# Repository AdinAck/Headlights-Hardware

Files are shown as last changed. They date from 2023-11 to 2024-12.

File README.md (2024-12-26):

# Headlights-Hardware

This repo contains the PCB design files for the headlights board.



# Design Considerations

- high voltage compliance required great care for component selection and stray interactions
- the very high switching frequency of the half-bridge made the position and proximity of the components very important
- device failures must result in a safe state

---
[Firmware](https://github.com/AdinAck/Headlights-Firmware) | [App](https://github.com/AdinAck/Headlights-App)

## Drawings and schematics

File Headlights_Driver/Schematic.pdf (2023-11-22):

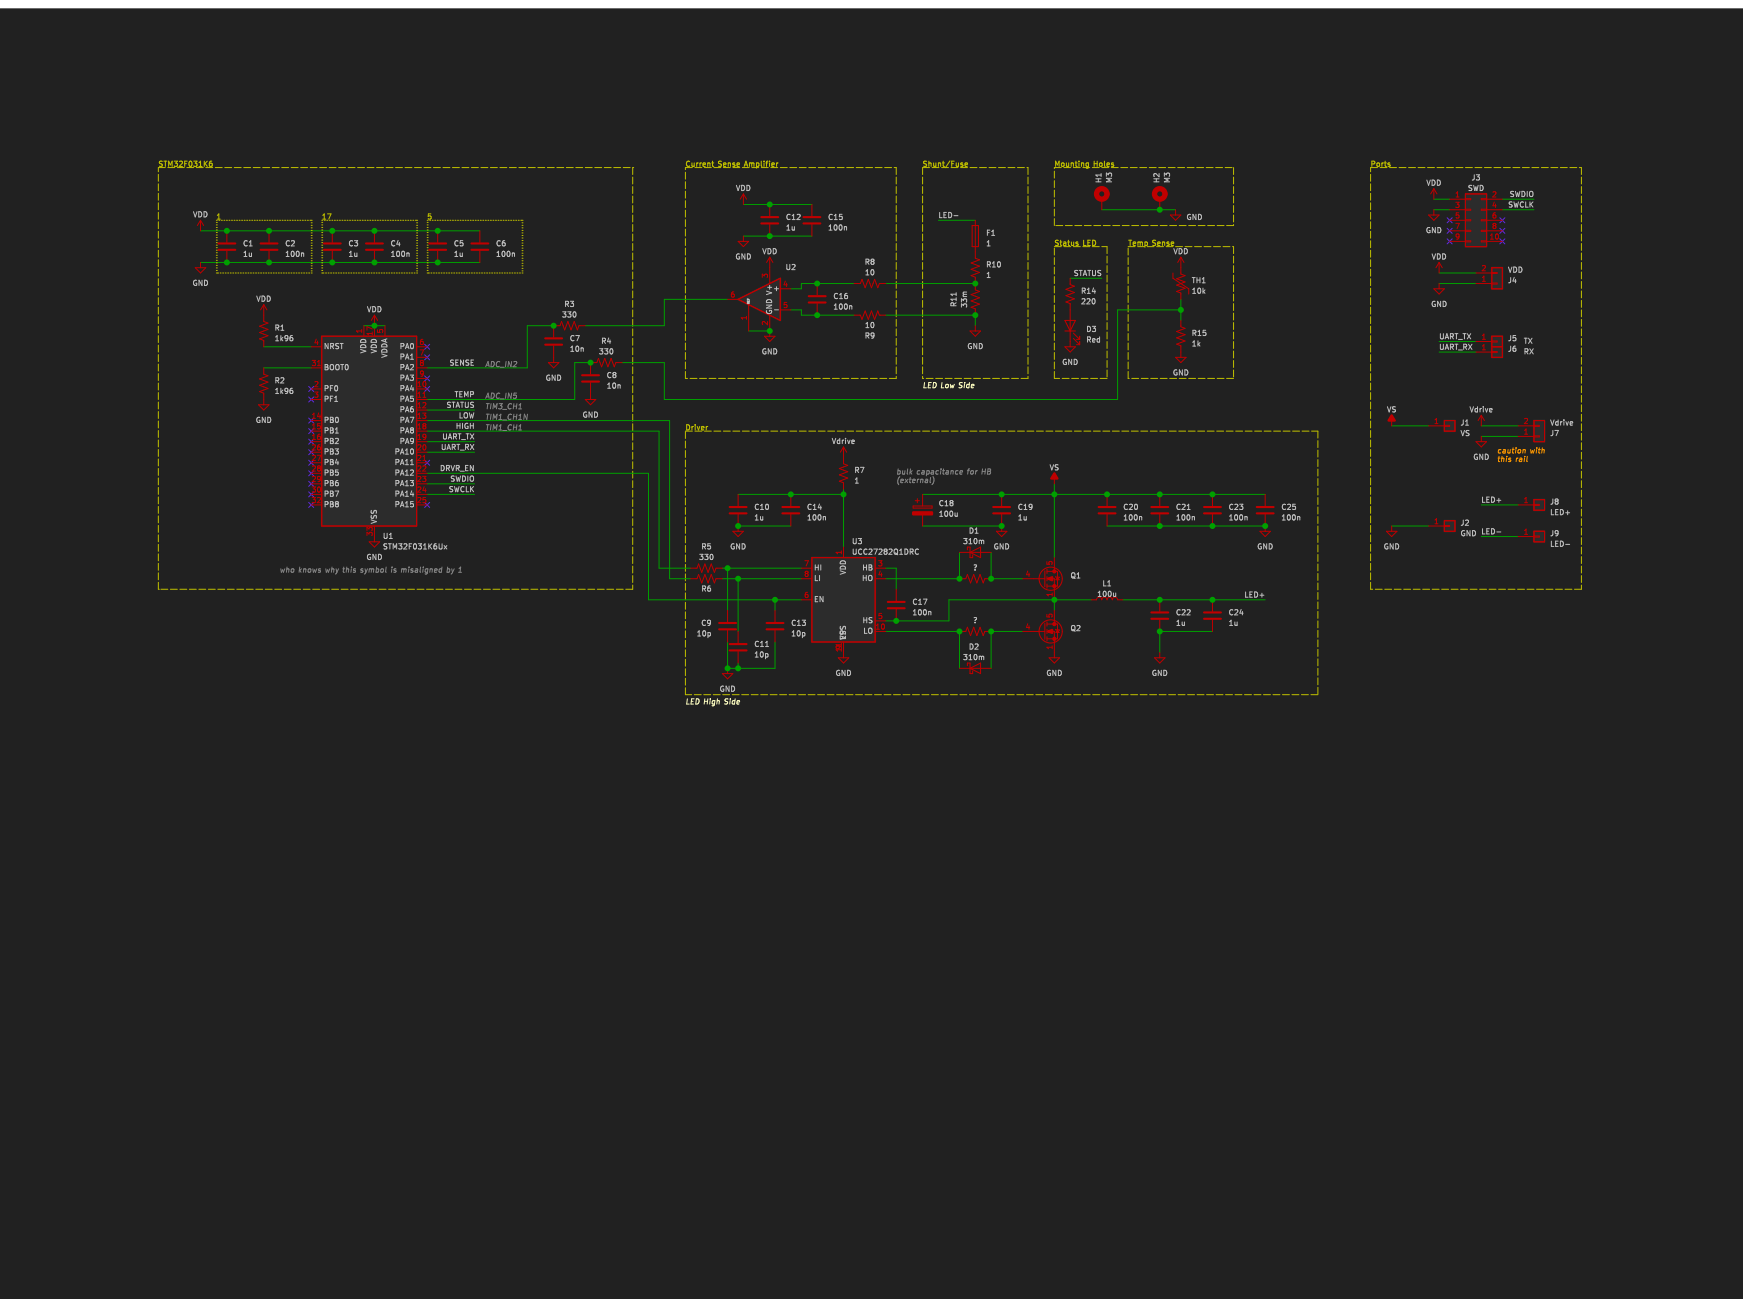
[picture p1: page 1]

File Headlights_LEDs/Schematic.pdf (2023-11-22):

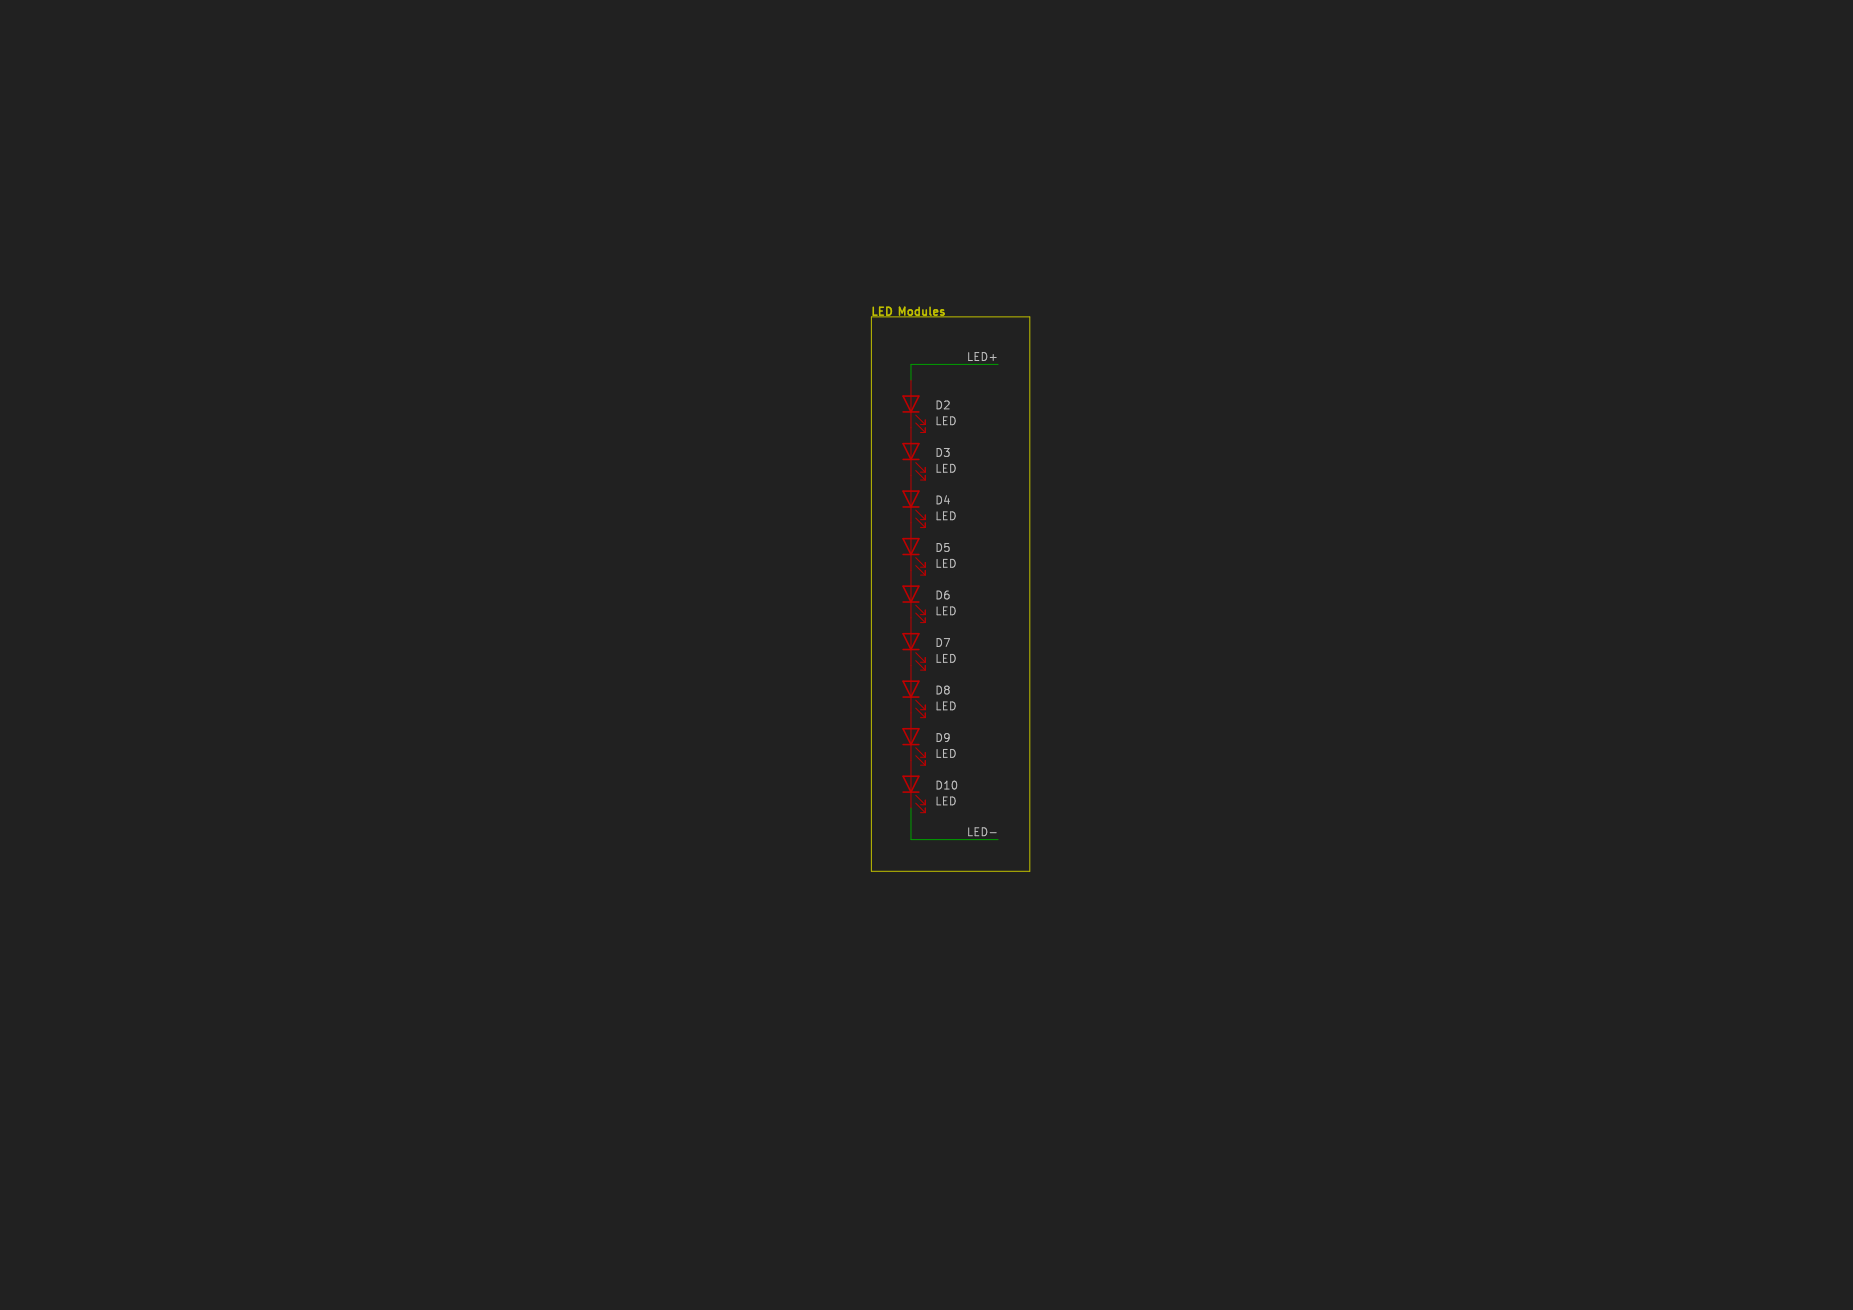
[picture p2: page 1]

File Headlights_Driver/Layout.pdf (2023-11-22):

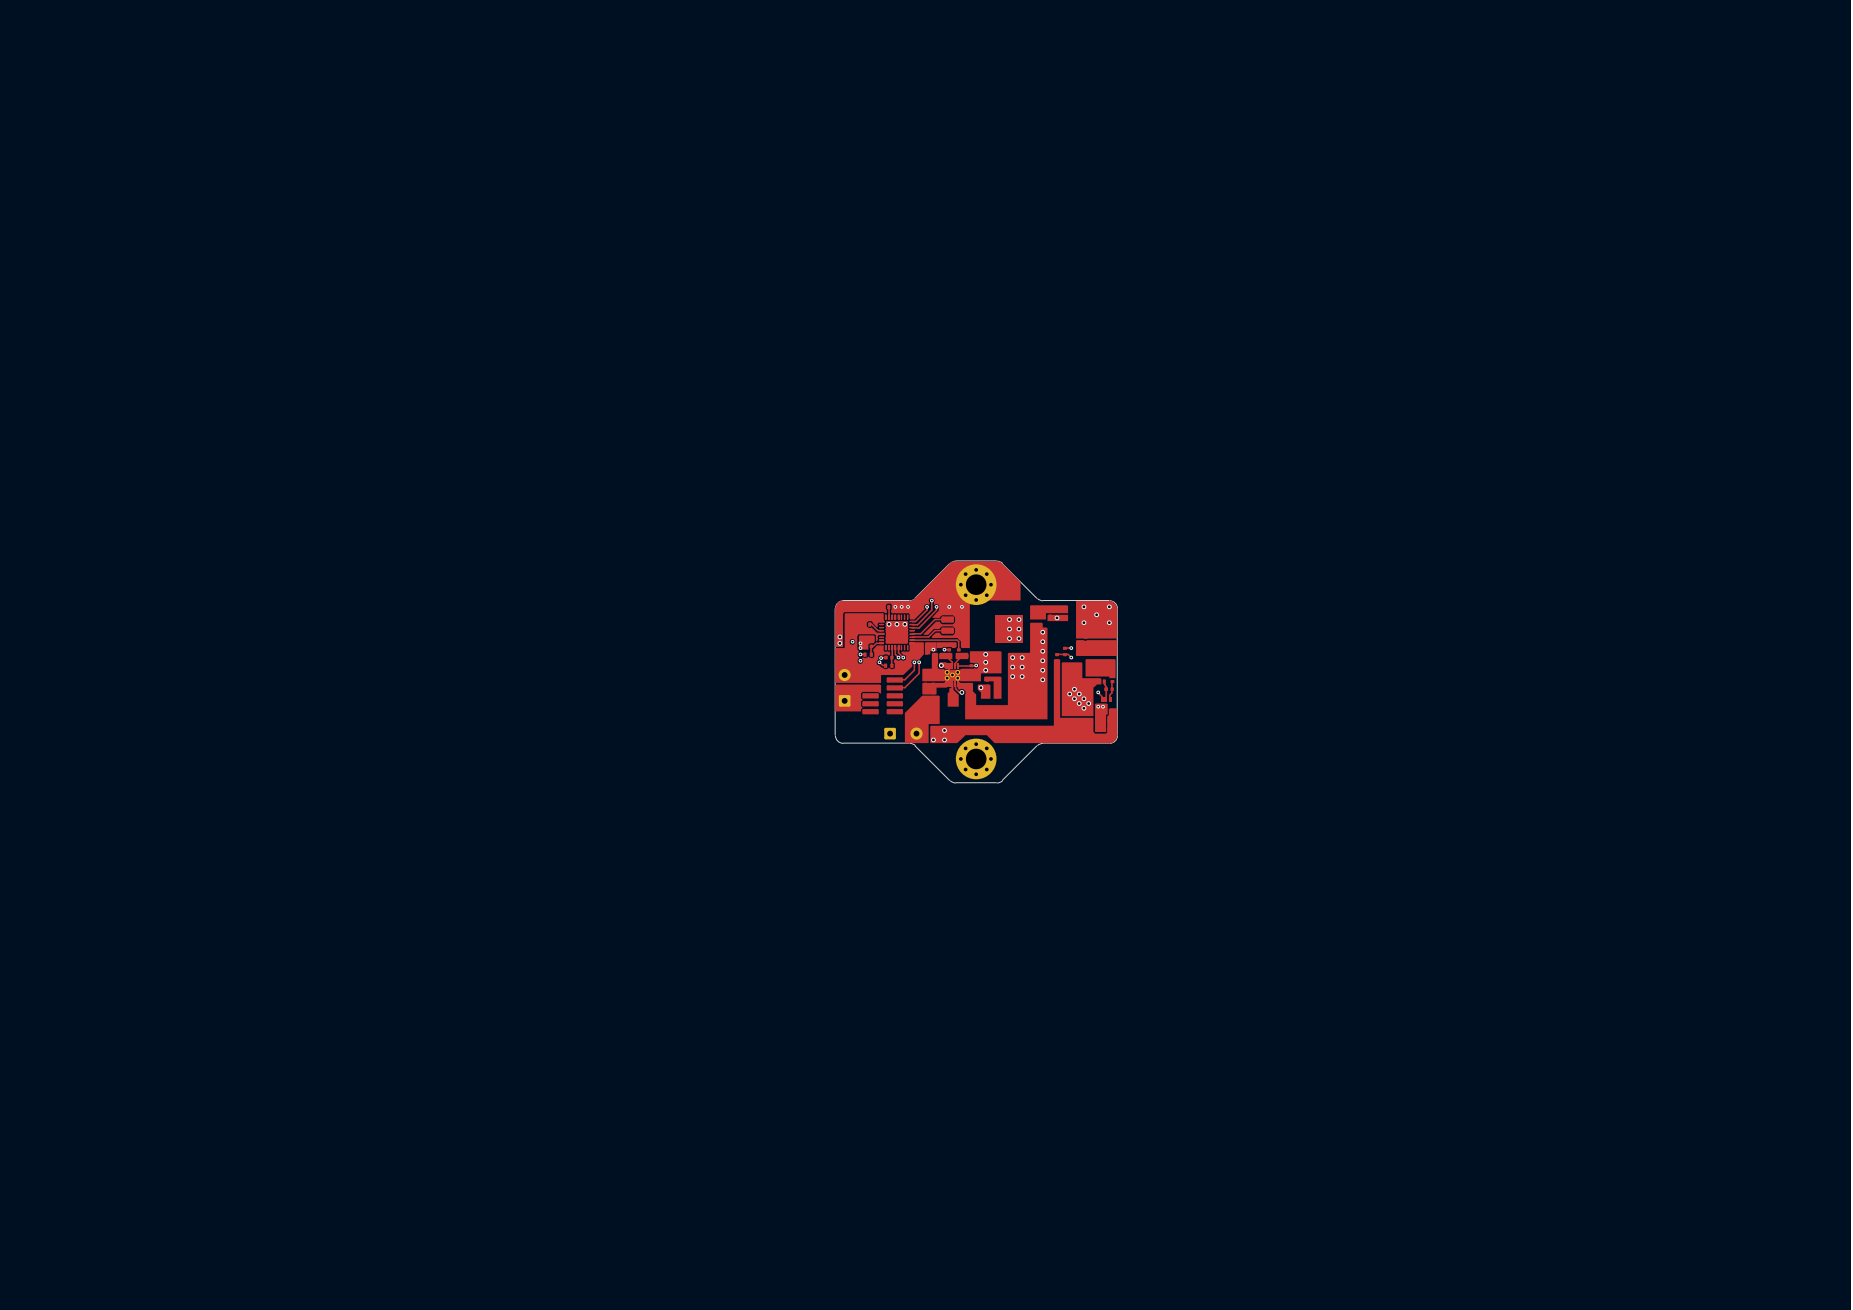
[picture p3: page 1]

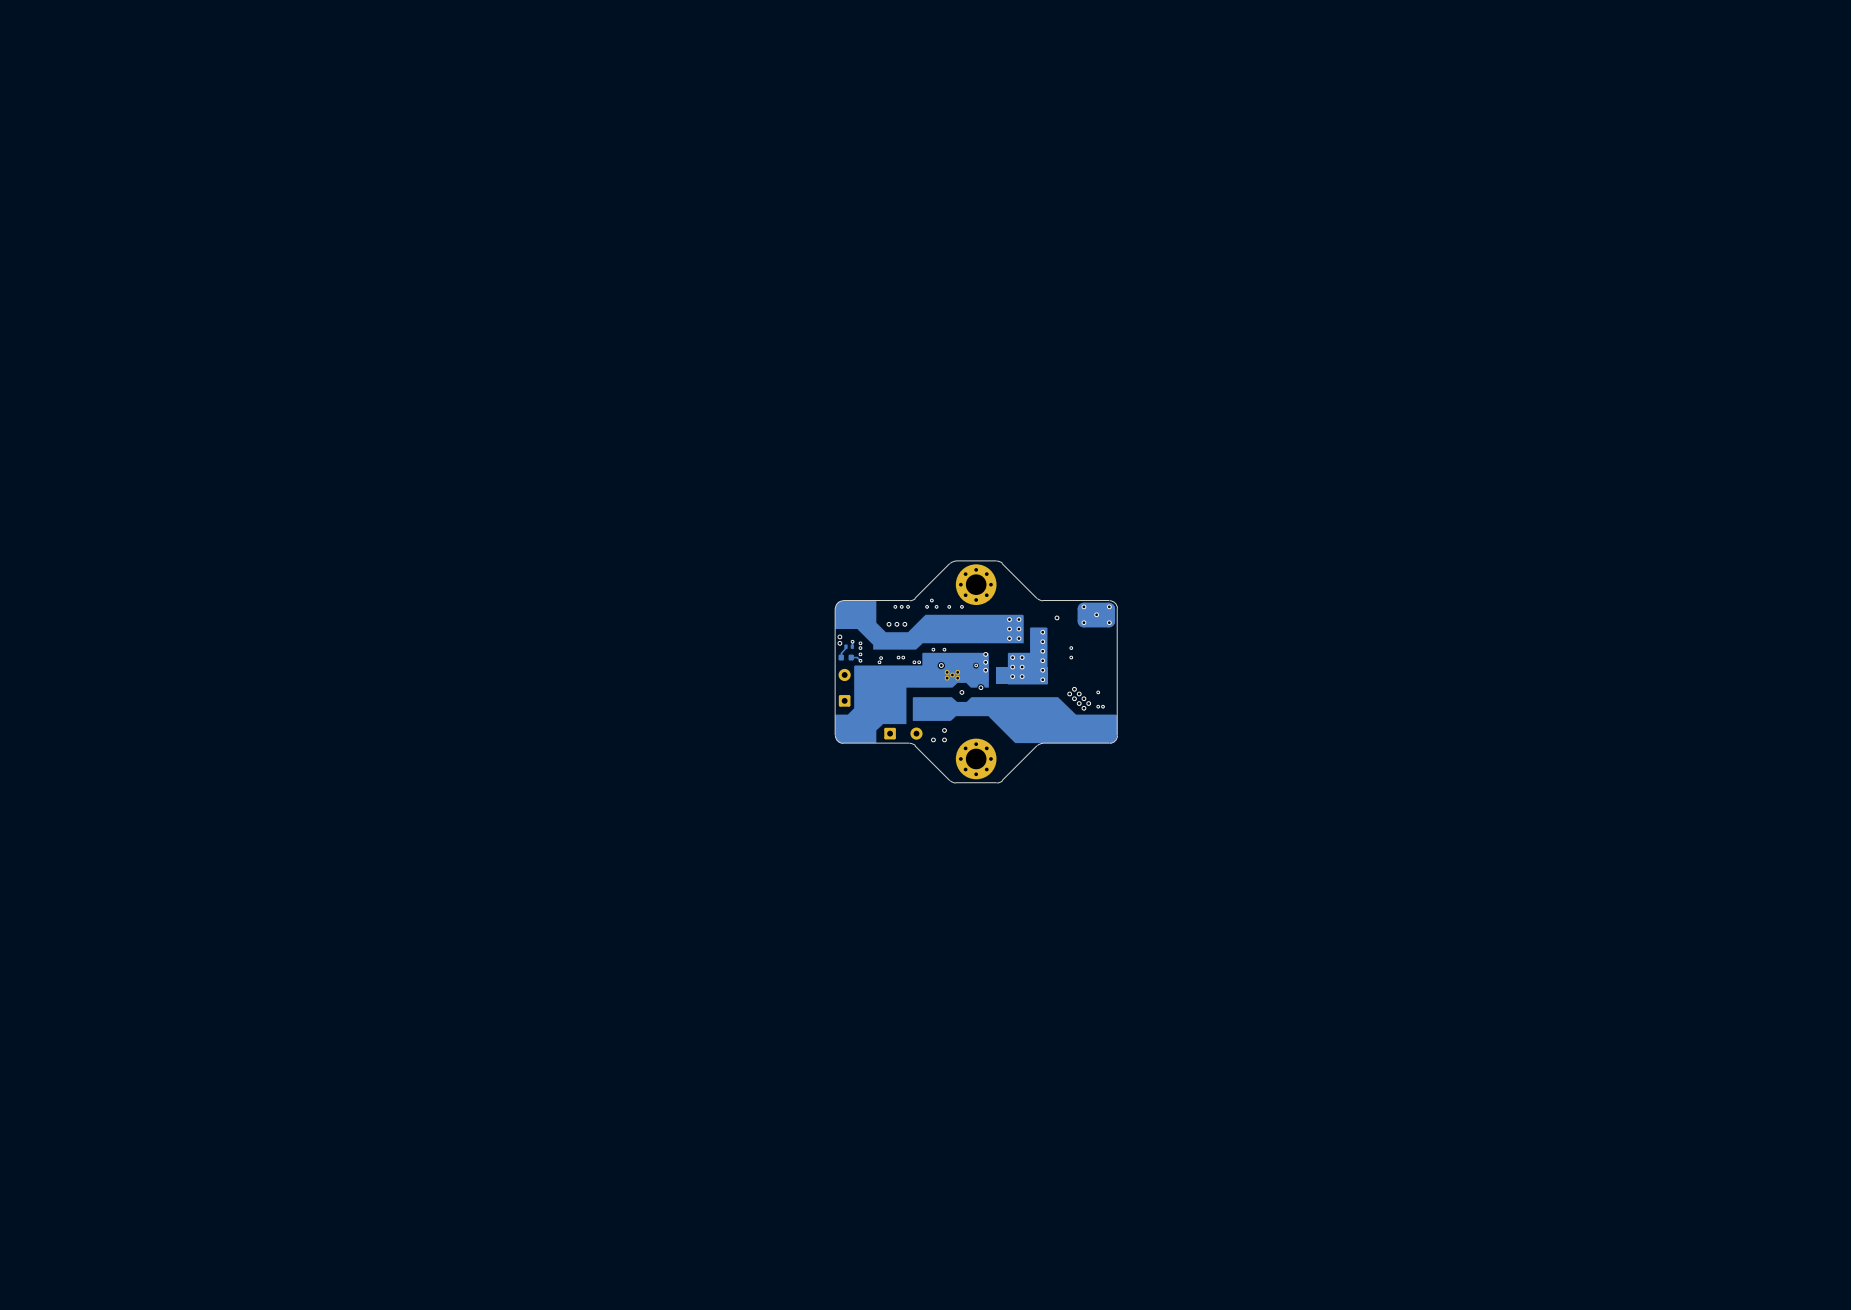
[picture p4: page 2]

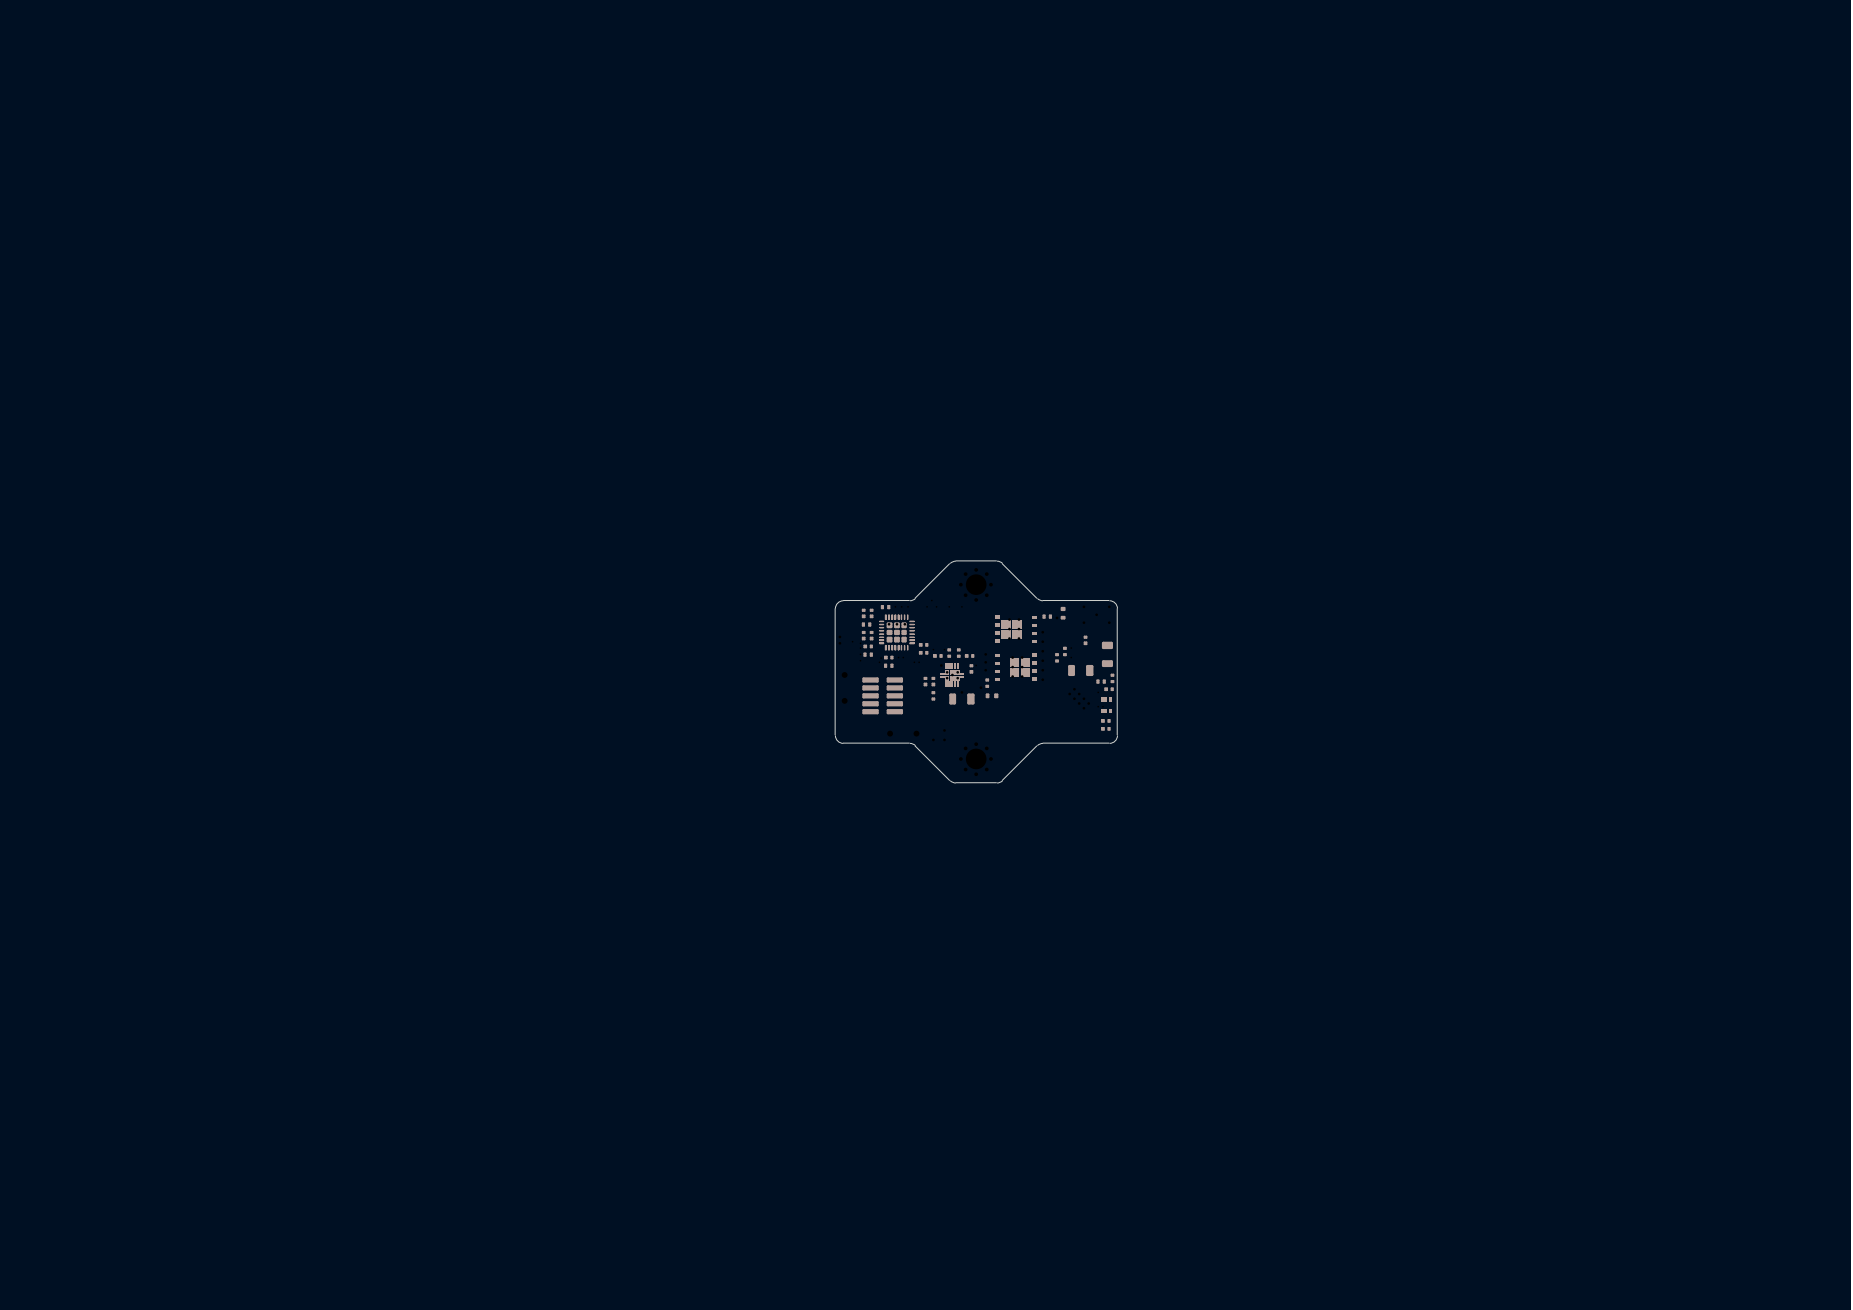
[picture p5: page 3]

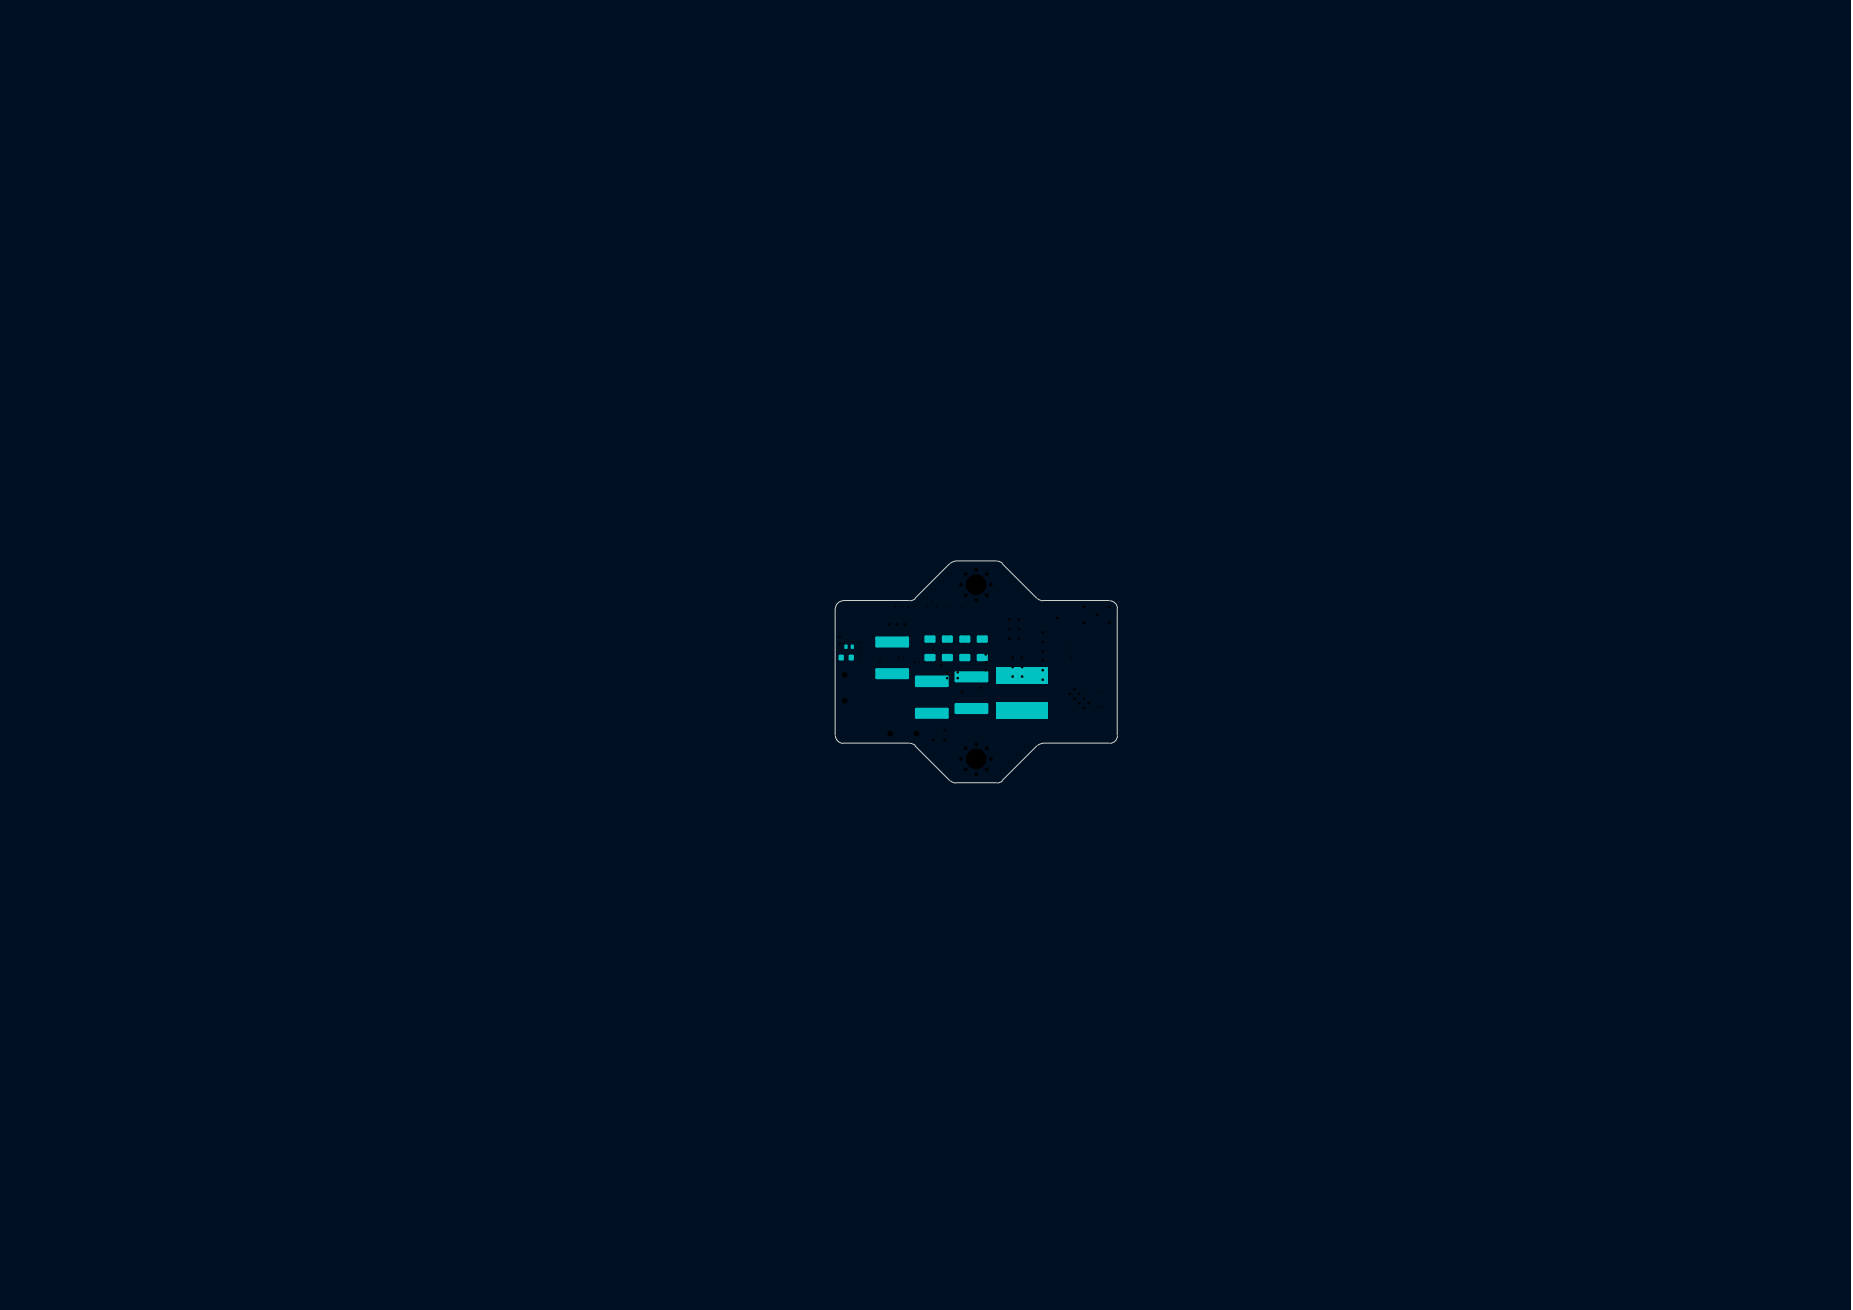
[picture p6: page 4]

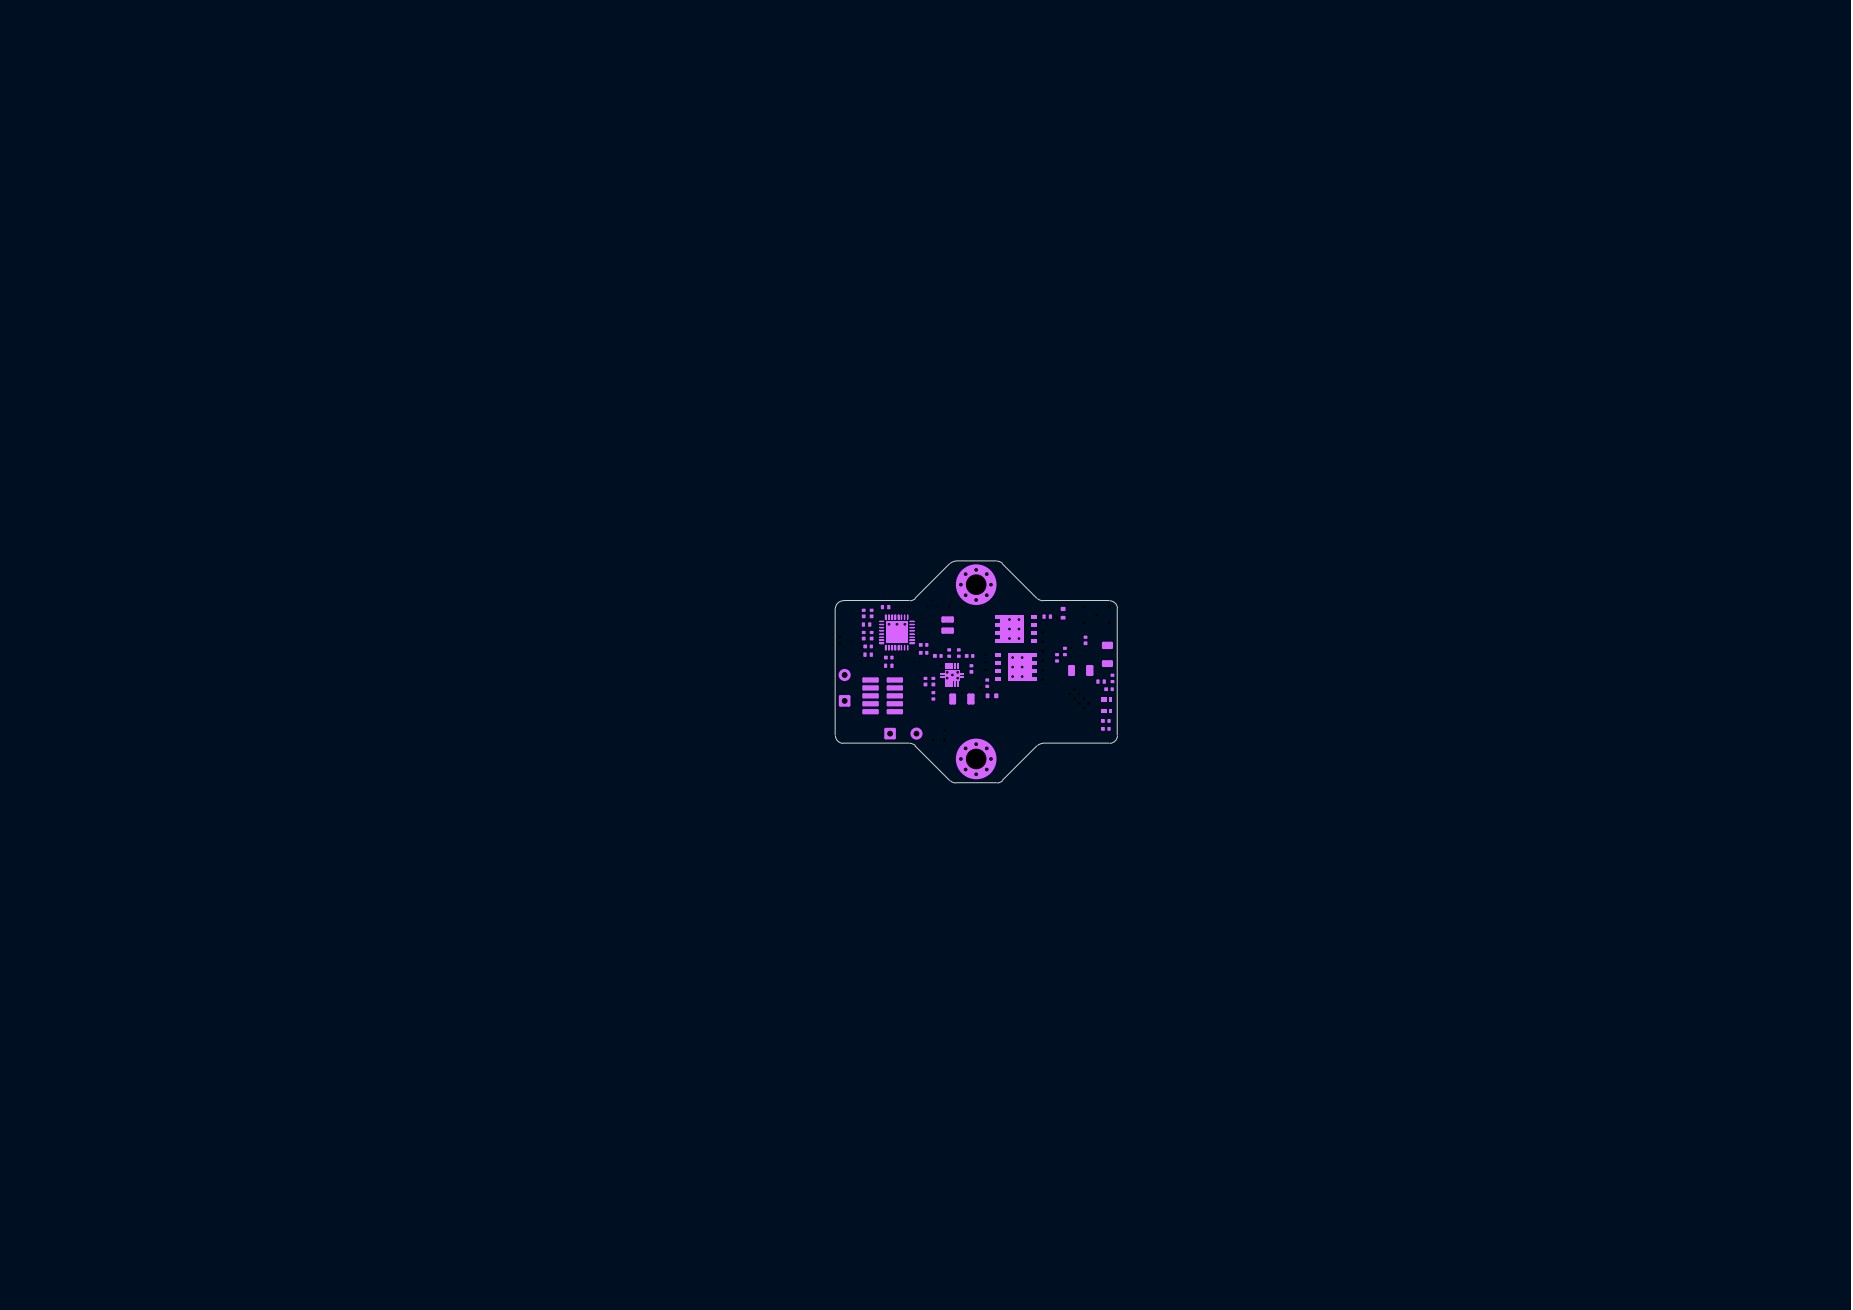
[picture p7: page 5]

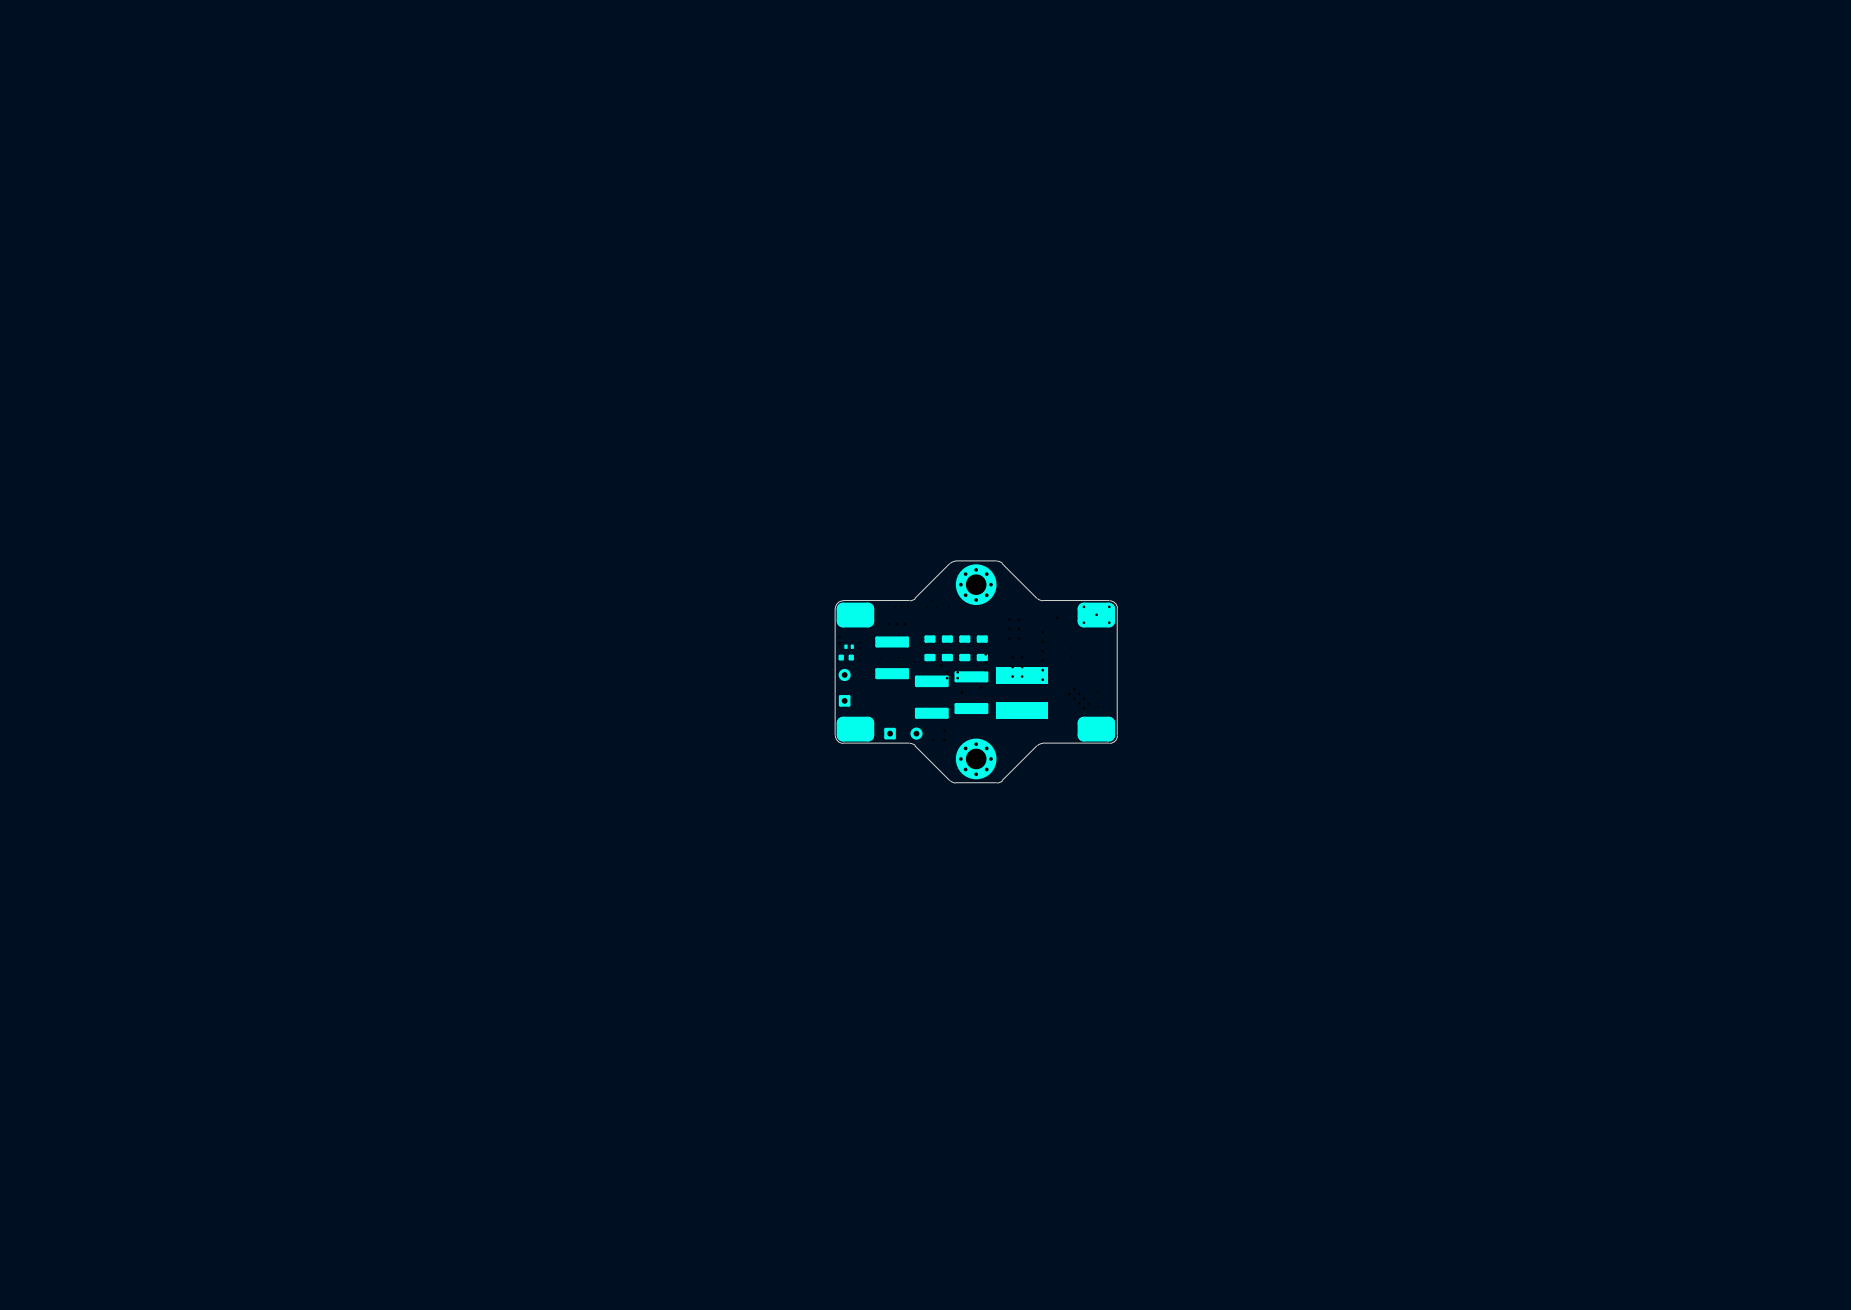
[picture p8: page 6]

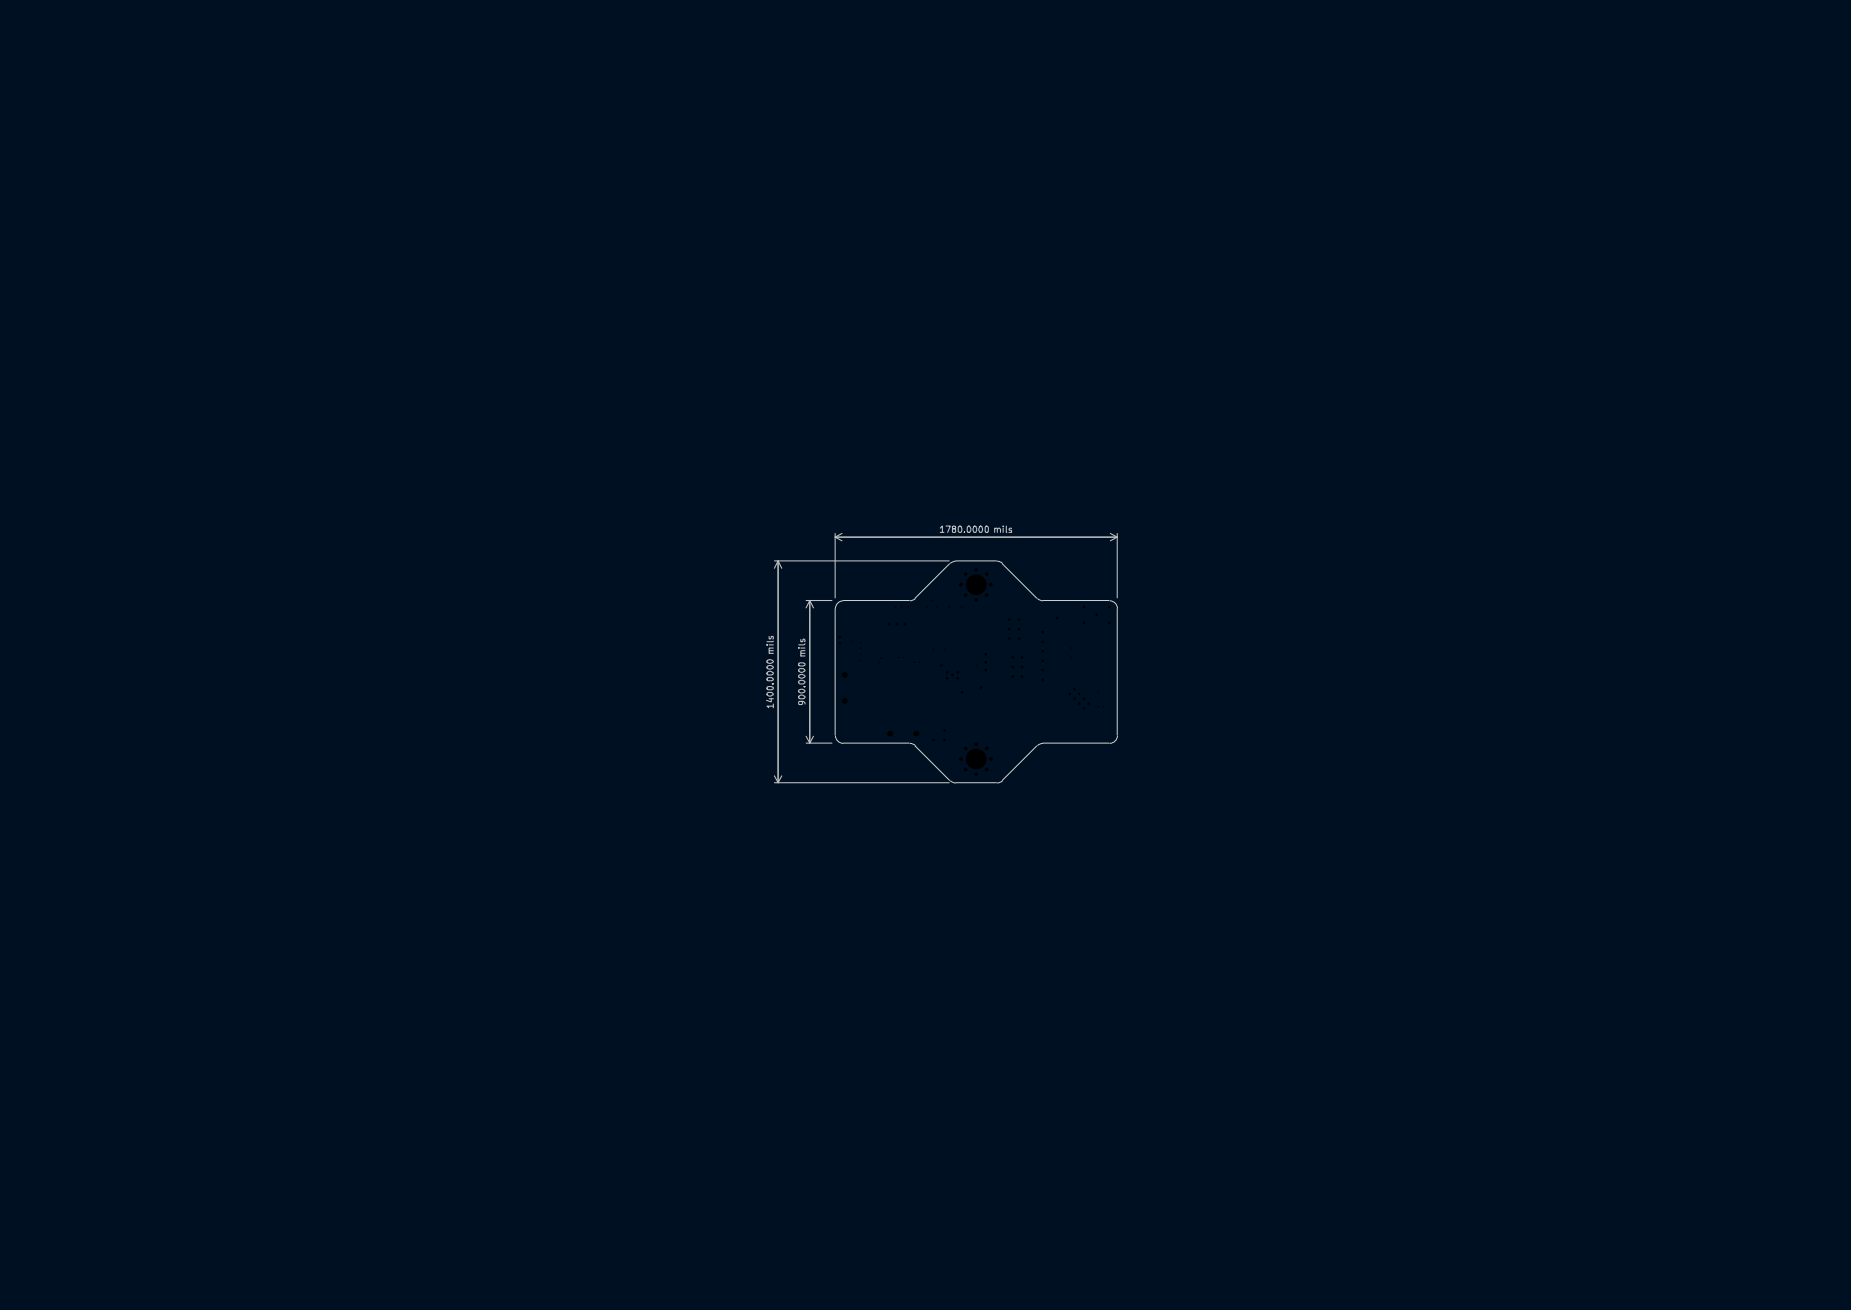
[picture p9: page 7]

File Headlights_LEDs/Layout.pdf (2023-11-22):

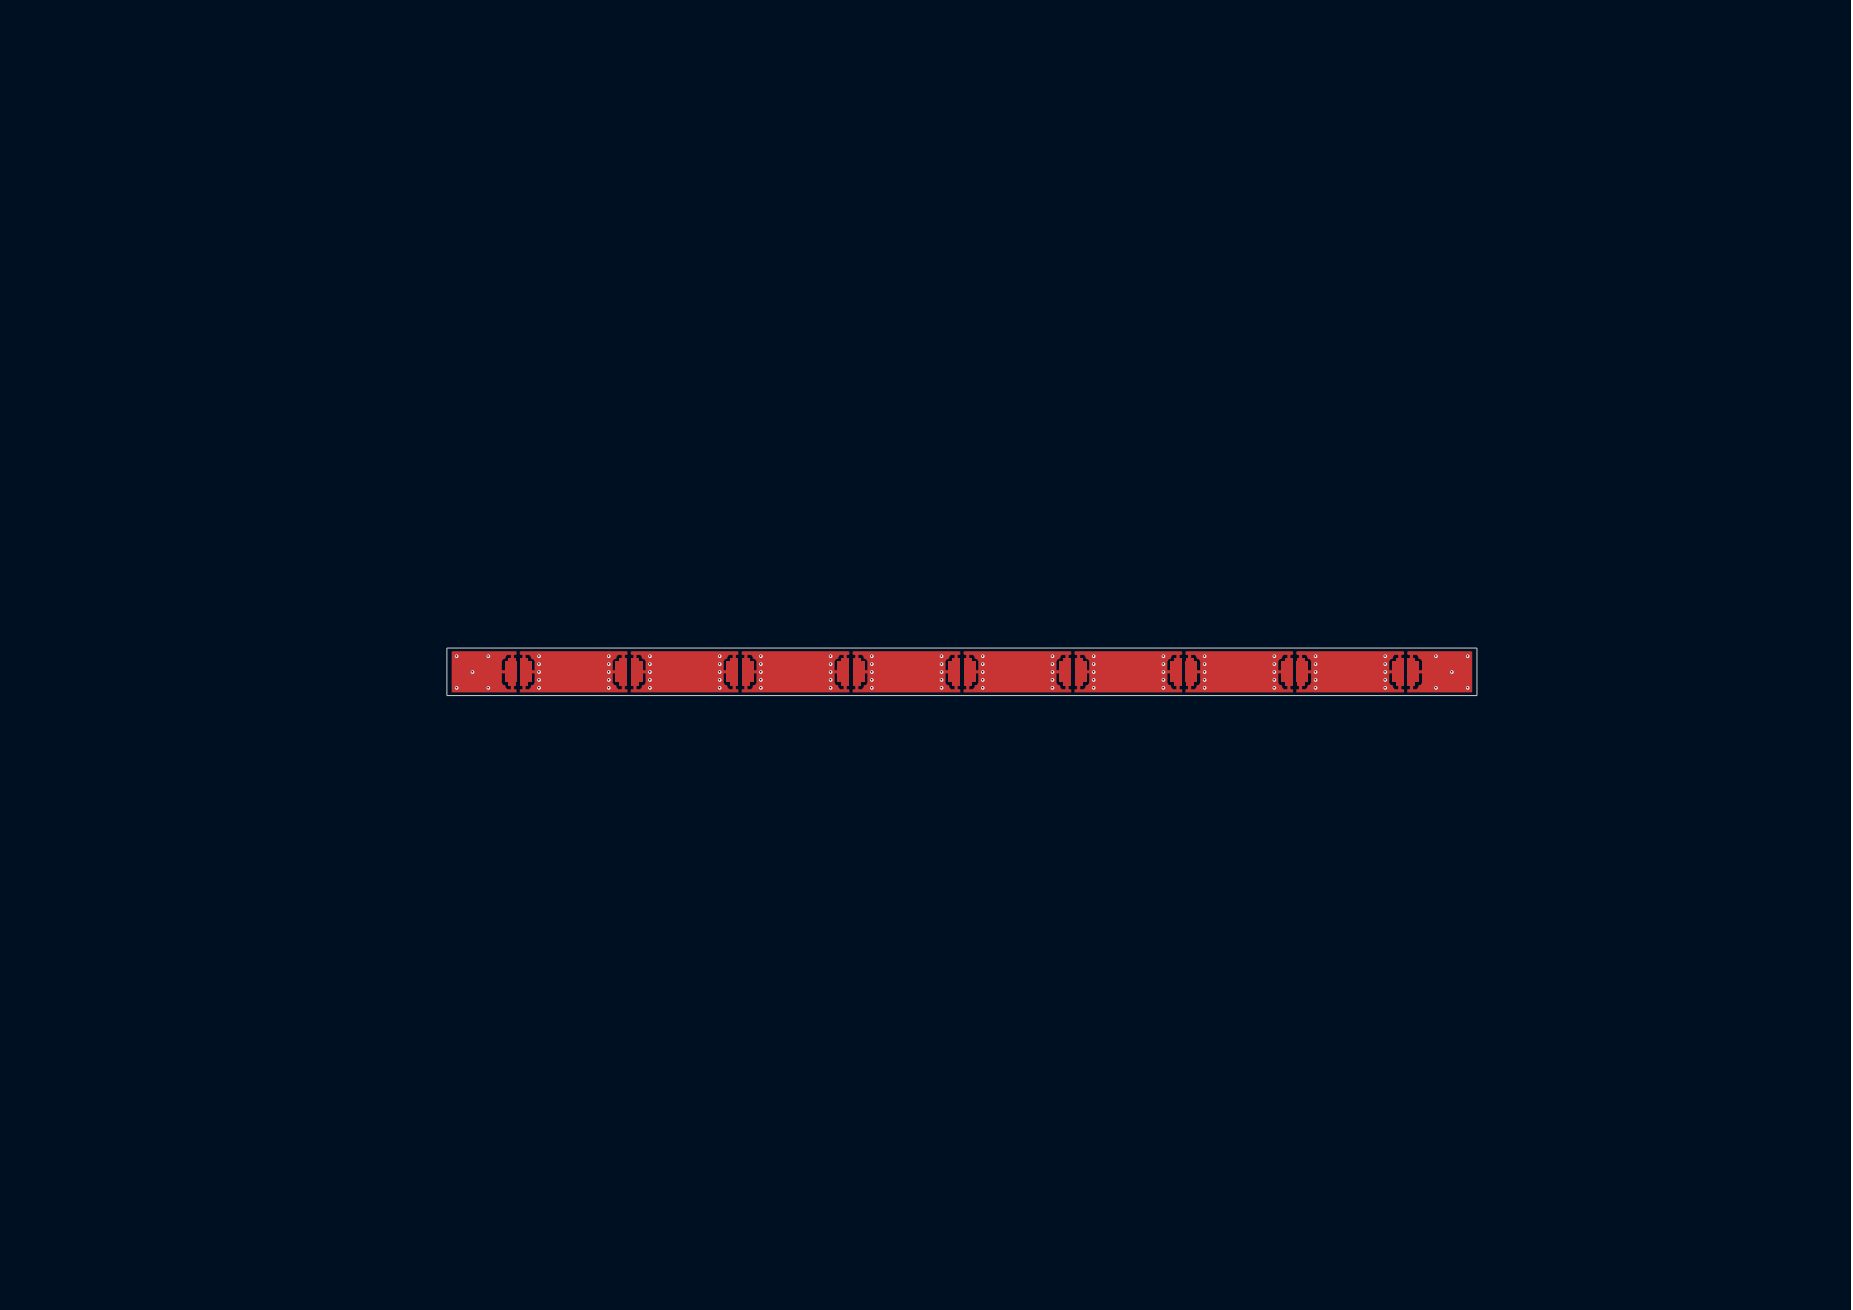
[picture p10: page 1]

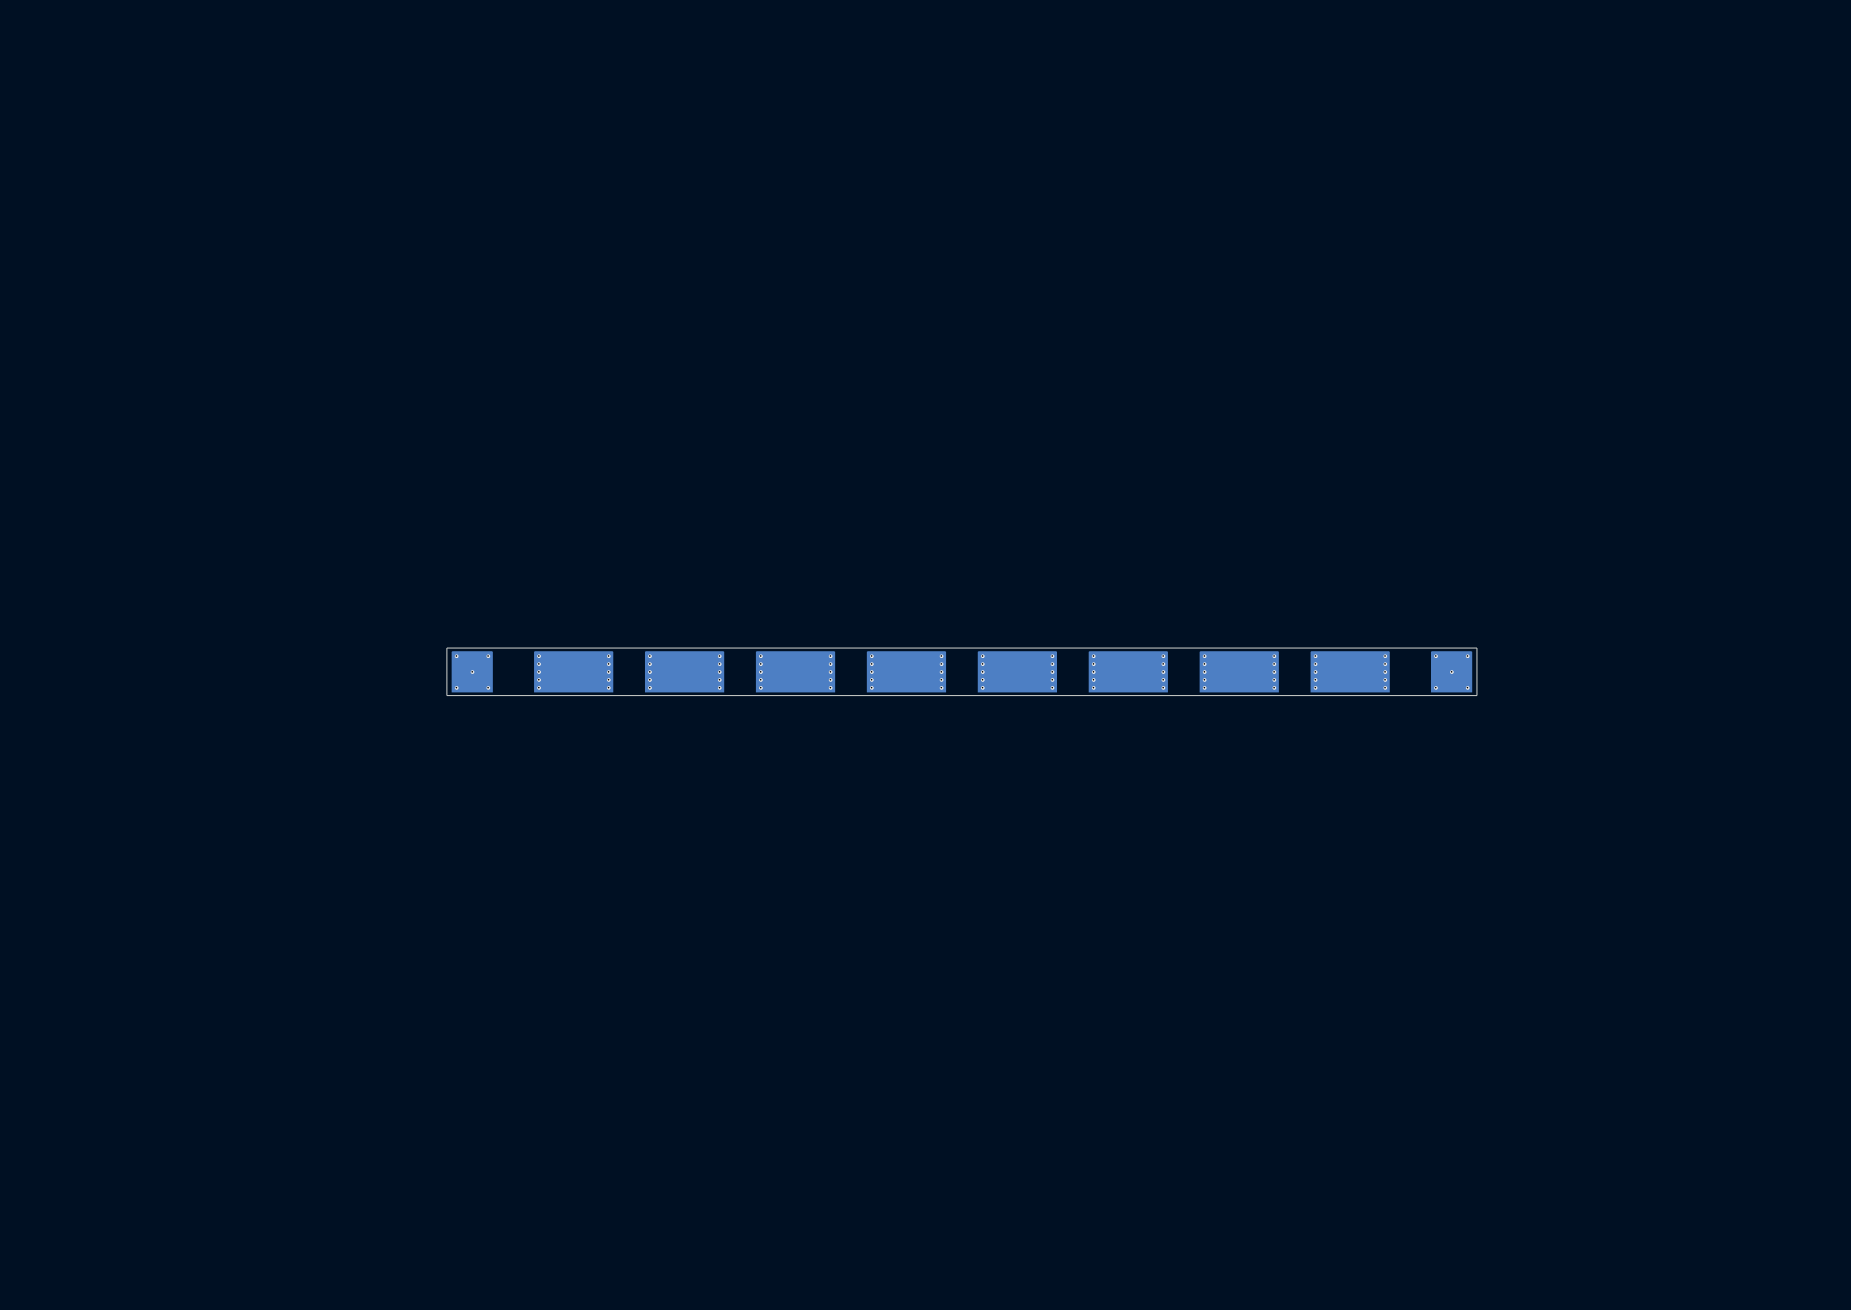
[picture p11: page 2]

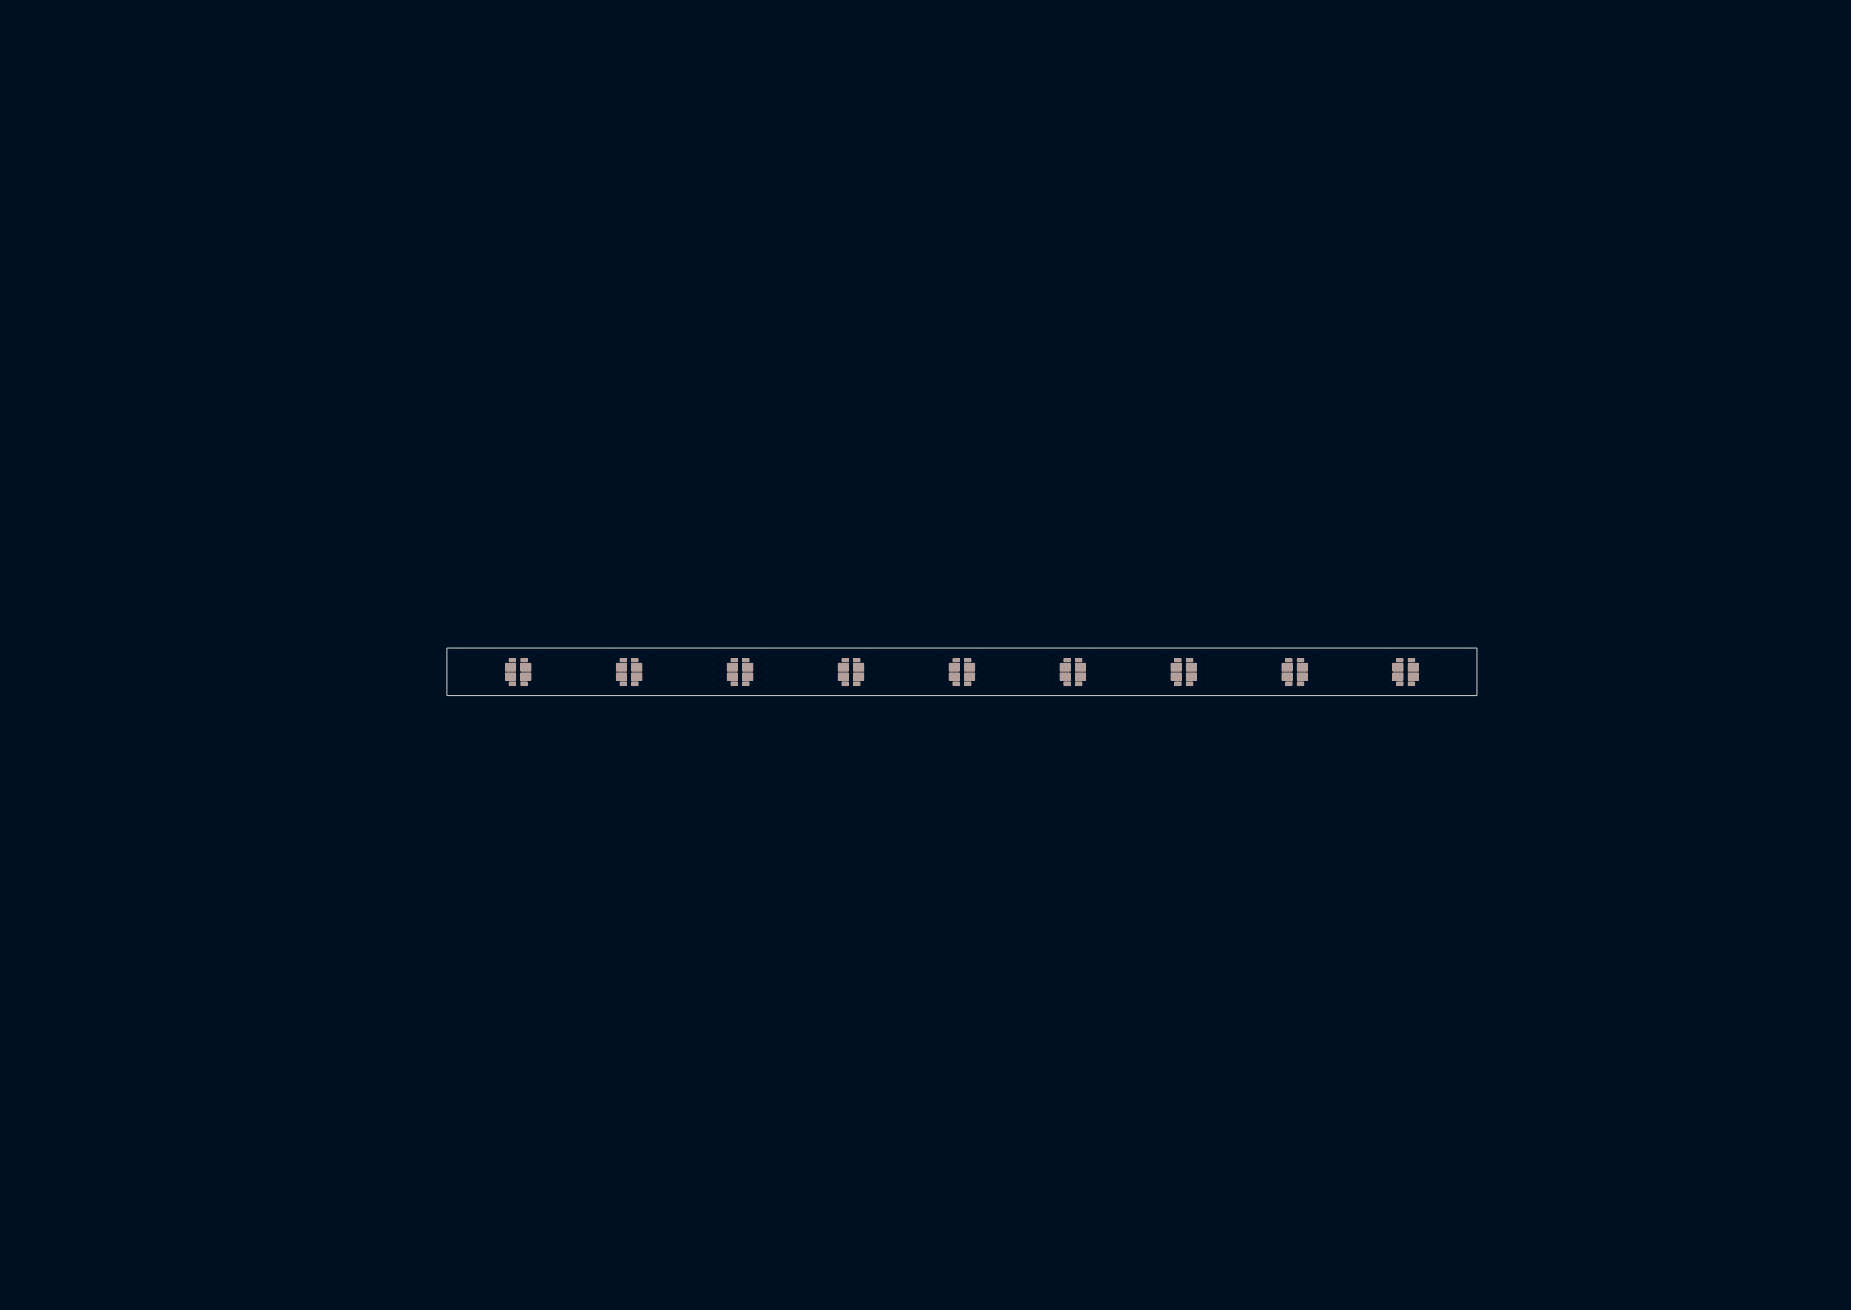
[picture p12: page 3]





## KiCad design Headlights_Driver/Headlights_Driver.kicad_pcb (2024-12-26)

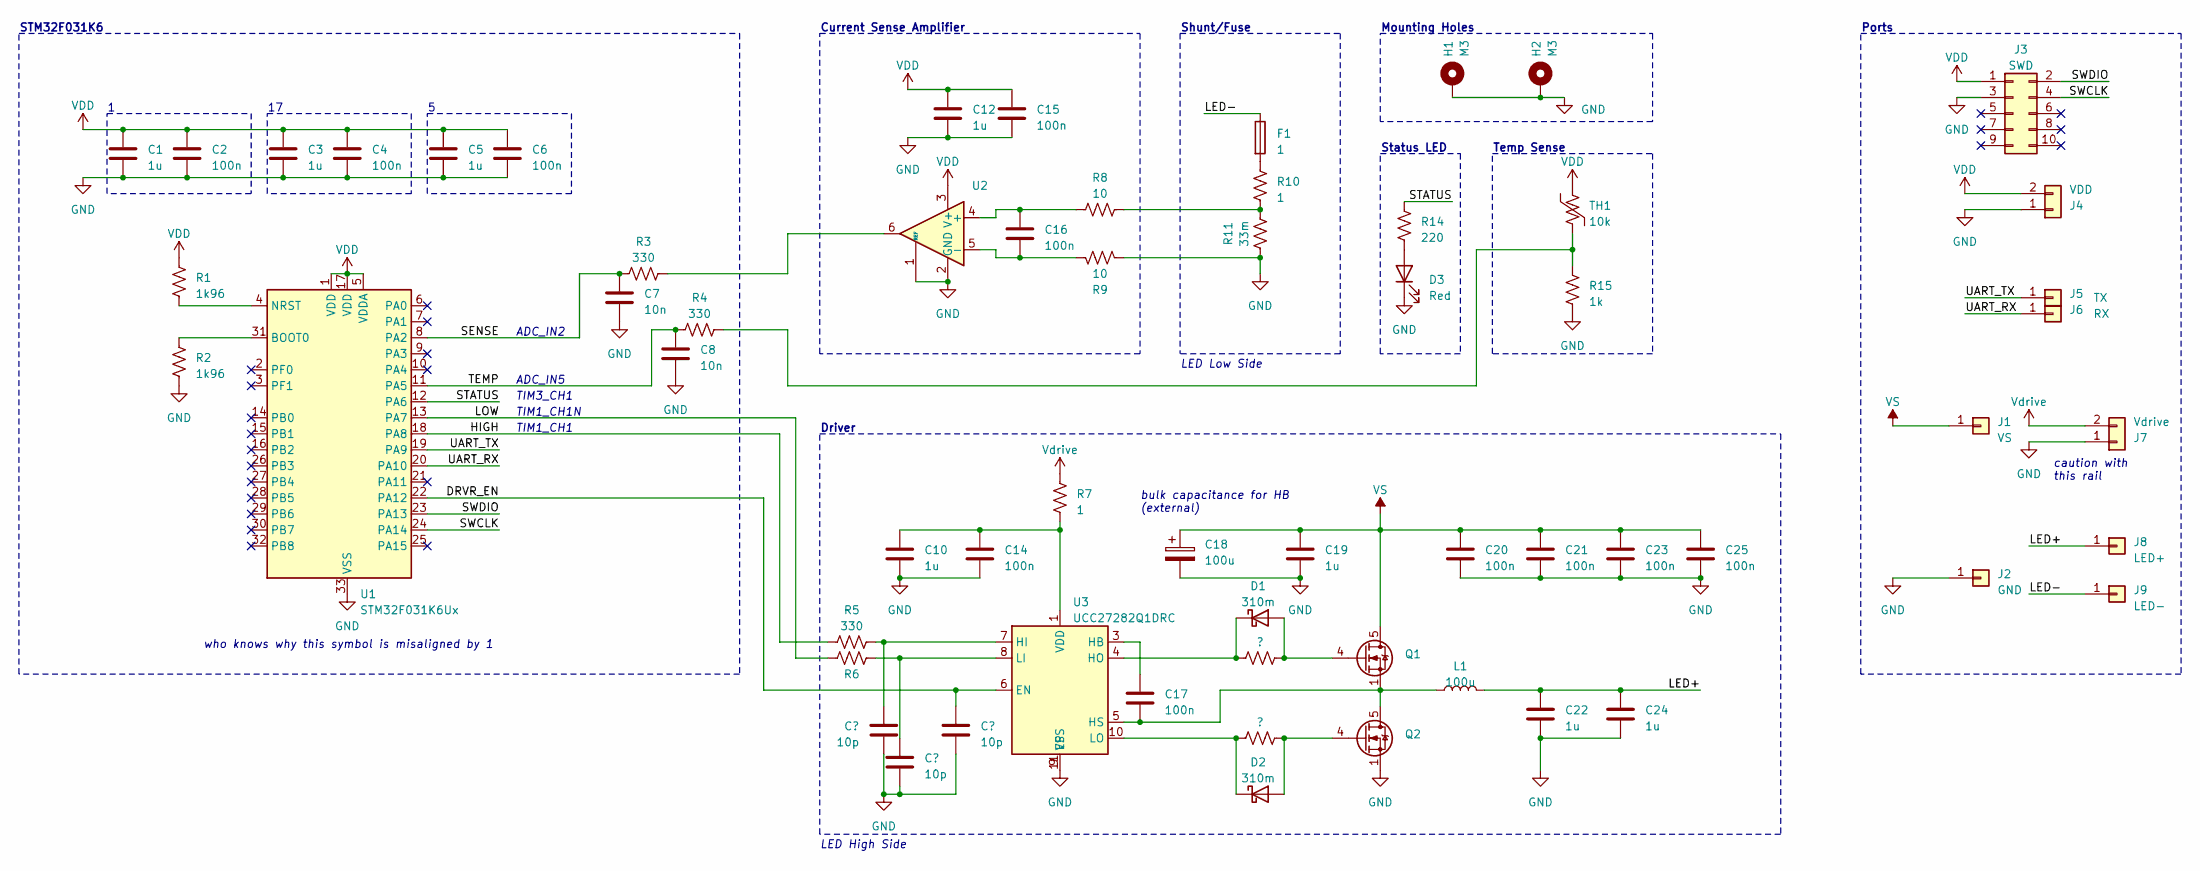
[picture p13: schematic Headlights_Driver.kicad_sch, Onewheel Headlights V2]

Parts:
C1, C3, C5, C10, C12: 1u; C_0402_1005Metric
C2, C4, C6, C14, C15, C16: 100n; C_0402_1005Metric
C7, C8: 10n; C_0402_1005Metric
C9, C11, C13: 10p; C_0402_1005Metric
C17, C20, C21, C23, C25: 100n; C_1206_3216Metric
C18: 100u
C19, C22, C24: 1u; C_2220_5650Metric
D1, D2: 310m; D_SOD-523
D3: Red; LED_0603_1608Metric
F1: 1; Fuse_0402_1005Metric
H1, H2: M3; MountingHole_3.2mm_M3_Pad_Via
J1: VS; SolderWirePad_1x01_SMD_4x6mm
J2: GND; SolderWirePad_1x01_SMD_4x6mm
J3: SWD; M50-3600542
J4: VDD; SolderWire-0.25sqmm_1x02_P4.2mm_D0.65mm_OD1.7mm
J5: TX; SolderWirePad_1x01_SMD_1x2mm
J6: RX; SolderWirePad_1x01_SMD_1x2mm
J7: Vdrive; SolderWire-0.25sqmm_1x02_P4.2mm_D0.65mm_OD1.7mm
J8: LED+; SolderWirePad_1x01_SMD_4x6mm
J9: LED-; SolderWirePad_1x01_SMD_4x6mm
L1: 100u; L_Bourns-SRN8040_8x8.15mm
Q1, Q2: BSC190N12NS3G; TDSON-8-1
R1, R2: 1k96; R_0402_1005Metric
R3, R4, R5, R6: 330; R_0402_1005Metric
R7: 1; R_0402_1005Metric
R8, R9: 10; R_0402_1005Metric
R10: 1; R_1206_3216Metric
R11: 33m; R_1206_3216Metric
R12, R13: ?; R_0402_1005Metric
R14: 220; R_0402_1005Metric
R15: 1k; R_0402_1005Metric
TH1: 10k; R_0402_1005Metric
U1: STM32F031K6Ux; QFN-32-1EP_5x5mm_P0.5mm_EP3.45x3.45mm
U2: INA199A2DCKR; SOT-363_SC-70-6
U3: UCC27282Q1DRC; VSON-10-1EP_3x3mm_P0.5mm_EP1.65x2.4mm_ThermalVias

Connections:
/DRVR_EN: C13.1, U1.22 (PA12), U3.6 (EN)
/HIGH: R5.1, U1.18 (PA8)
/LED+: C22.1, C24.1, J8.1, L1.2
/LED-: F1.1, J9.1
/LOW: R6.2, U1.13 (PA7)
/SENSE: C7.1, R3.1, U1.8 (PA2)
/STATUS: R14.1, U1.12 (PA6)
/SWCLK: J3.4, U1.24 (PA14)
/SWDIO: J3.2, U1.23 (PA13)
/TEMP: C8.1, R4.1, U1.11 (PA5)
/UART_RX: J6.1, U1.20 (PA10)
/UART_TX: J5.1, U1.19 (PA9)
GND: C1.2, C2.2, C3.2, C4.2, C5.2, C6.2, C7.2, C8.2, C9.2, C10.2, C11.2, C12.2, C13.2, C14.2, C15.2, C18.2, C19.2, C20.2, C21.2, C22.2, C23.2, C24.2, C25.2, D3.1 (K), H1.1, H2.1, J2.1, J3.3, J4.1, J7.1, Q2.1 (S), Q2.2 (S), Q2.3 (S), R2.2, R9.2, R11.2, R15.2, U1.33 (VSS), U2.1 (REF), U2.2 (GND), U3.9 (VSS), U3.11 (EP)
unnamed: D1.2 (A), Q1.4 (G), R12.2
unnamed: D1.1 (K), R12.1, U3.4 (HO)
unnamed: D2.2 (A), Q2.4 (G), R13.2
unnamed: D2.1 (K), R13.1, U3.10 (LO)
unnamed: D3.2 (A), R14.2
unnamed: F1.2, R10.1
unnamed: C17.2, L1.1, Q1.1 (S), Q1.2 (S), Q1.3 (S), Q2.5 (D), U3.5 (HS)
unnamed: R3.2, U2.6
unnamed: R8.2, R10.2, R11.1
unnamed: R4.2, R15.1, TH1.2
unnamed: R2.1, U1.31 (BOOT0)
unnamed: R1.2, U1.4 (NRST)
unnamed: C16.1, R8.1, U2.4 (+)
unnamed: C16.2, R9.1, U2.5 (-)
unnamed: C17.1, U3.3 (HB)
unnamed: C9.1, R5.2, U3.7 (HI)
unnamed: C11.1, R6.1, U3.8 (LI)
unnamed: C10.1, C14.1, R7.1, U3.1 (VDD)
VDD: C1.1, C2.1, C3.1, C4.1, C5.1, C6.1, C12.1, C15.1, J3.1, J4.2, R1.1, TH1.1, U1.1 (VDD), U1.5 (VDDA), U1.17 (VDD), U2.3 (V+)
VS: C18.1, C19.1, C20.1, C21.1, C23.1, C25.1, J1.1, Q1.5 (D)
Vdrive: J7.2, R7.2

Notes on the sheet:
Current Sense Amplifier
ADC_IN5
Ports
Shunt/Fuse
STM32F031K6
caution with this rail
LED Low Side
TIM3_CH1
Driver
bulk capacitance for HB (external)
Status LED
TIM1_CH1N
LED High Side
ADC_IN2
TIM1_CH1
Mounting Holes
who knows why this symbol is misaligned by 1
Temp Sense

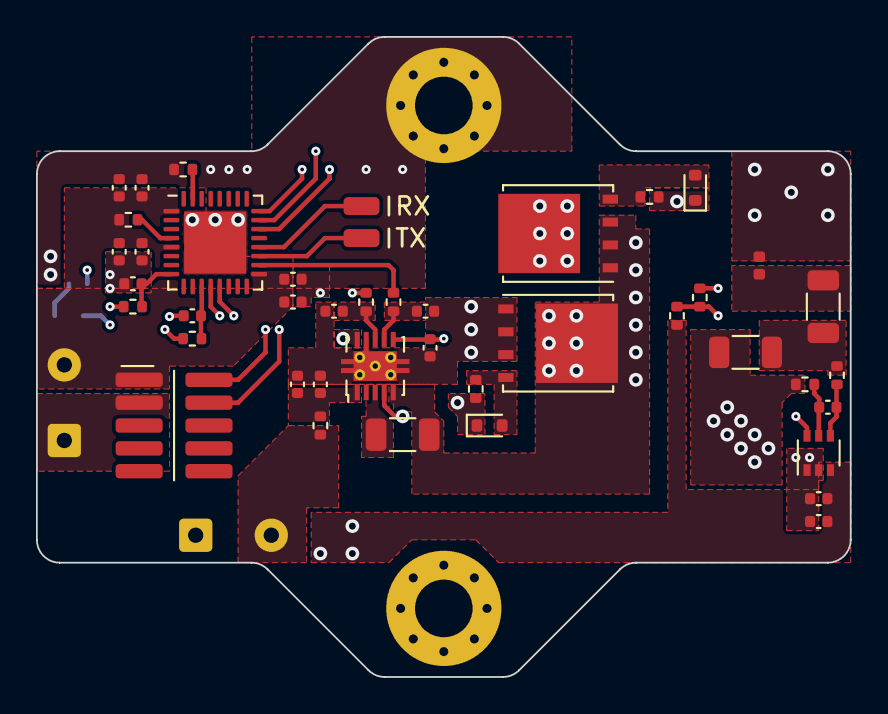
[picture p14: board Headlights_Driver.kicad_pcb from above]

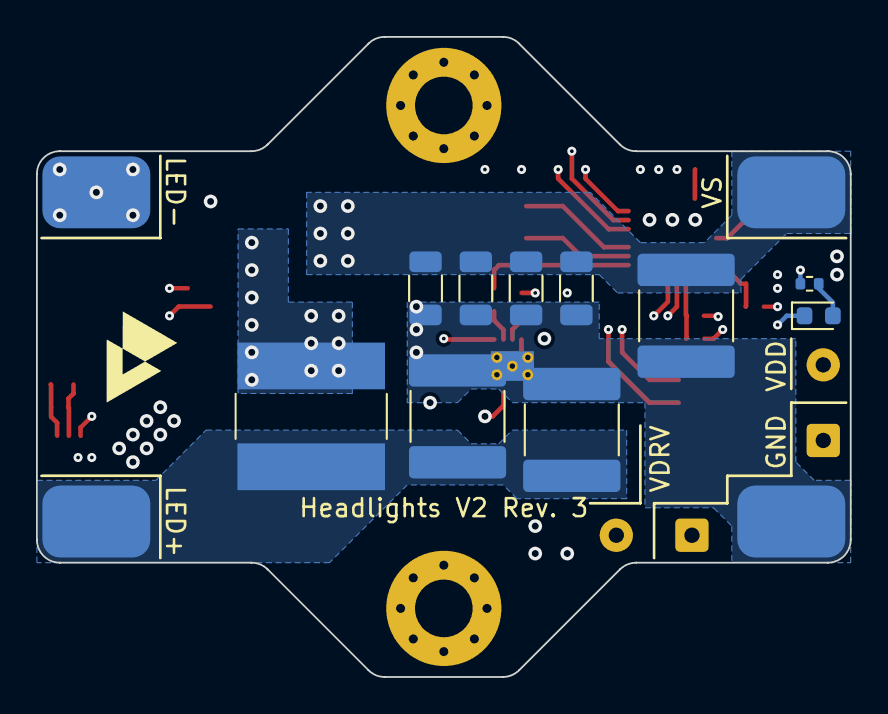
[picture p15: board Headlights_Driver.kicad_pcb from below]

Board: 4 copper layers, 45.2 x 35.6 mm, 61 parts (16 on the bottom side), 34 nets.

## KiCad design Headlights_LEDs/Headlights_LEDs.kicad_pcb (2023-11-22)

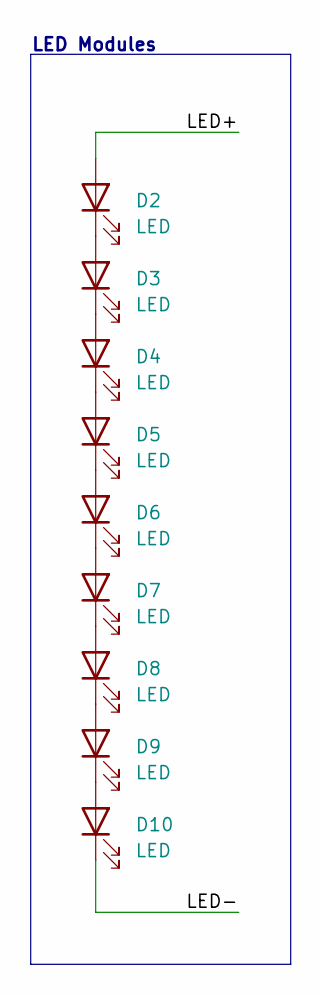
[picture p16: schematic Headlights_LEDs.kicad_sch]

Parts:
D2, D3, D4, D5, D6, D7, D8, D9, D10: LED; LED_5050; Part L150-40905006000S0

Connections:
/LED+: D2.2 (A)
/LED-: D10.1 (K)
unnamed: D2.1 (K), D3.2 (A)
unnamed: D3.1 (K), D4.2 (A)
unnamed: D4.1 (K), D5.2 (A)
unnamed: D5.1 (K), D6.2 (A)
unnamed: D6.1 (K), D7.2 (A)
unnamed: D7.1 (K), D8.2 (A)
unnamed: D8.1 (K), D9.2 (A)
unnamed: D9.1 (K), D10.2 (A)

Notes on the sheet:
LED Modules

Board: 2 copper layers, 9 parts (0 on the bottom side), 8 nets, no tracks yet.
